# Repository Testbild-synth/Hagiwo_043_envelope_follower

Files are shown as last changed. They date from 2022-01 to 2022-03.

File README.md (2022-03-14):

# Hagiwo Eurorack Envelope Follower
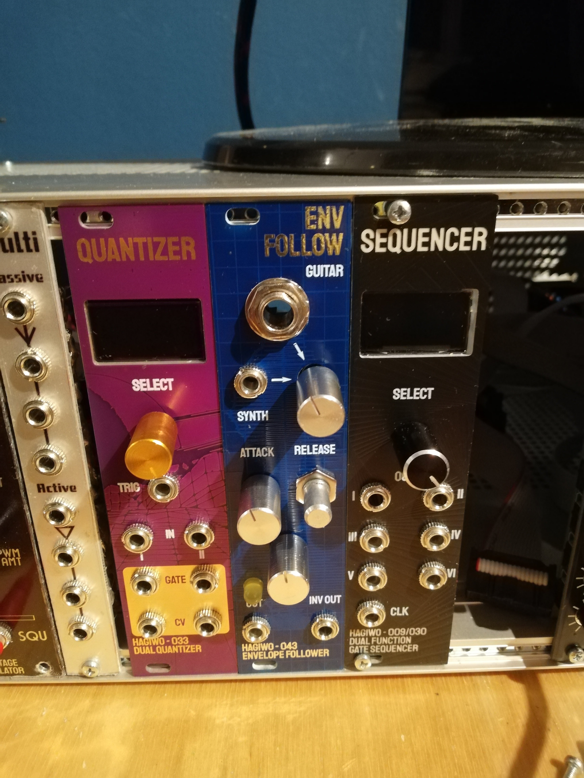
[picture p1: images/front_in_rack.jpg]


This project is a through hole PCB version the HAGIWO 043 envelope follower. I also added a guitar jack input with more amplification to be able to plug in a variety of instruments.

## STATUS: CONFIRMED WORKING! Currently on version 2, if you ordered an older version make sure that the ground connector is correctly connected to all other pcb grounds and also check that the Guitar input is going into the C3 capacitor correctly.

## Hardware and PCB
For this one I wanted to fit it all onto one PCB and make the guitar jack fit. This was quite a task and I'm afraid the pcb ended up a bit messy in the end because of this. It still works fine, but has a lot of overlapping components and you have to be careful when building it.

You can find the schematic and BOM in the root folder. 
For the PCBs, the module has one circuit PCB and one panel PCB. 
You can order them on any common PCB manufacturing service, I used JLCPCB. For the circuit PCB, standard settings should be fine.
For the panel, since it has copper exposed, make sure to choose a lead free surface finish (LeadFree HASL, ENIG) and/or spraypaint your panels so that you don't get lead on your hands.

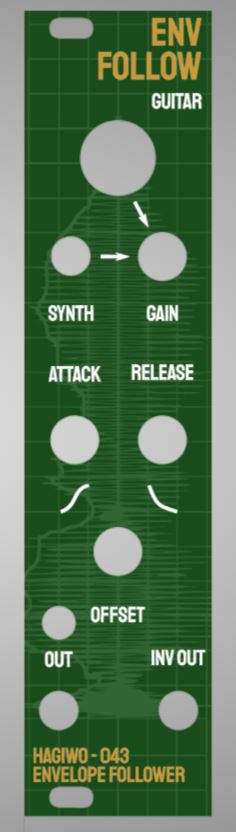
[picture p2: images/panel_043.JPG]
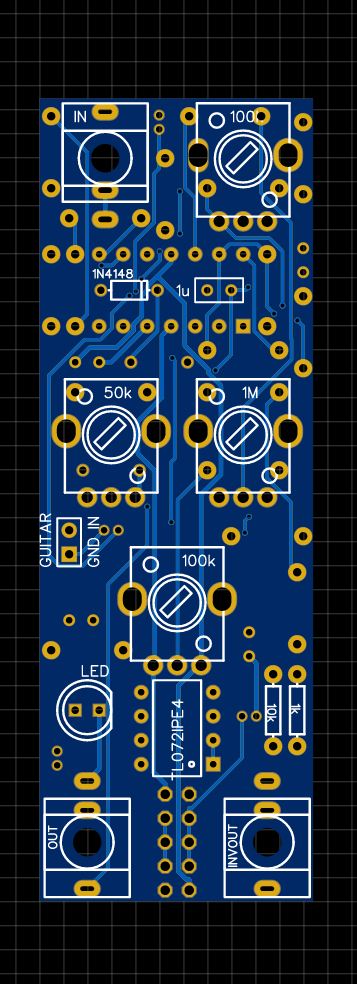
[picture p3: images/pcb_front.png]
 

For assembly, the guitar jack is optional. It will stick out and has to be connected to the rest of the pcb via wires. Look for the pads named "guitar in" and "gnd" on the pcb and connect those to the inner and outer log of a mono guitar/6.5mm jack socket.
Be sure to get a pcb mount guitar jack! we will not be mounting it to the pcb but the ["normal" round ones](https://www.conrad.de/de/p/bkl-electronic-1109001-klinken-steckverbinder-6-35-mm-buchse-einbau-vertikal-polzahl-num-2-mono-silber-1-st-732931.html) don't fit the spacing. I got [this!](https://www.reichelt.de/klinkeneinbaubuchse-6-3-mm-mono-2-pol-ebmsv-63-p36198.html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)

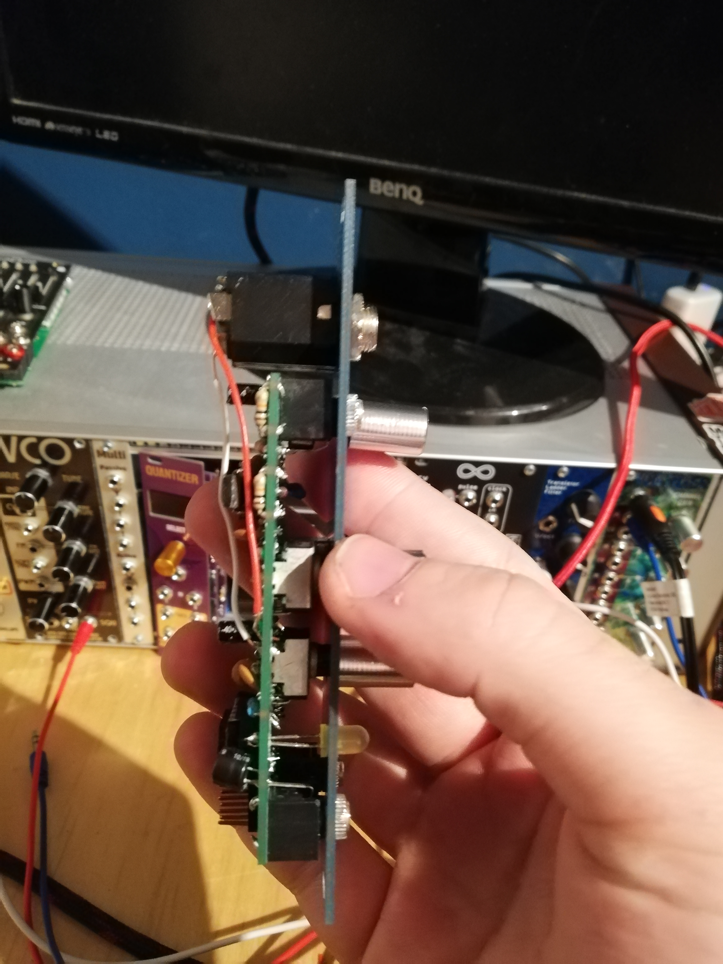
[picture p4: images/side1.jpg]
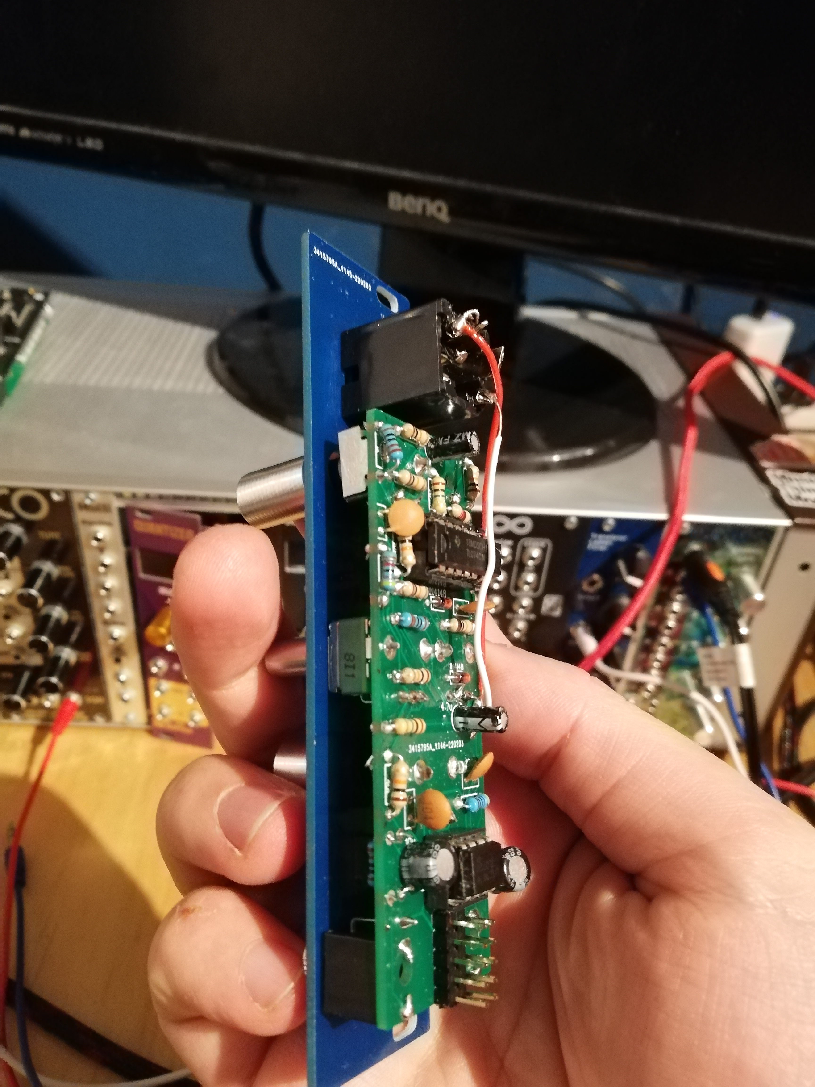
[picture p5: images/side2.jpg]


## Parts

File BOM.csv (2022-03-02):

Name | Designator | Footprint | Quantity | Comment
50k Potentiometer R09k | ATK | R09-5KΩ | 1
100k Potentiometer R09k | GAIN,OFFSET | R09-5KΩ | 2
1M Potentiometer R09k | REL | R09-5KΩ | 1
4.7u Electrolytic capacitor >25V | C1,C3 | CAP-D4.0×F1.5 | 2
1u ceramic capacitor | C2 | RAD-0.1 | 1
100n ceramic capacitor | C4,C6,C8,C9 | RAD-0.1 | 4
10u Electrolytic capacitor >25V | C5,C7 | CAP-D4.0×F1.5 | 2
1N4148 | D1,D2,D3 | SEEED-DO-35 | 3
Eurorack Power header | EP1 | EURORACK_POWER_V2 | 1
Guitar input Jack | H1 | HDR-F-2.54_1X2 | 1 | Preferably something like https://www.reichelt.de/klinkeneinbaubuchse-6-3-mm-mono-2-pol-ebmsv-63-p36198.html?r=1
Thonkiconn jack | J1,J2,J3 | THONKICONN_1 | 3
LED 5mm | LED1 | LED_LED5MM | 1
20k | R1 | R_AXIAL-0.3 | 1
22k | R2 | R_AXIAL-0.3 | 1
10k | R3,R7,R8,R9,R13,R14,R15,R16,R17 | R_AXIAL-0.3 | 10
47k | R4 | R_AXIAL-0.3 | 1
1k | R5,R12,R18 | R_AXIAL-0.3 | 3
1M | R6,R11 | R_AXIAL-0.3 | 2
4.7k | R10, R19 | R_AXIAL-0.3 | 2
TL074 DIP | U1 | DIP14 | 1
TL072 DIP | U2 | DIP8 | 1

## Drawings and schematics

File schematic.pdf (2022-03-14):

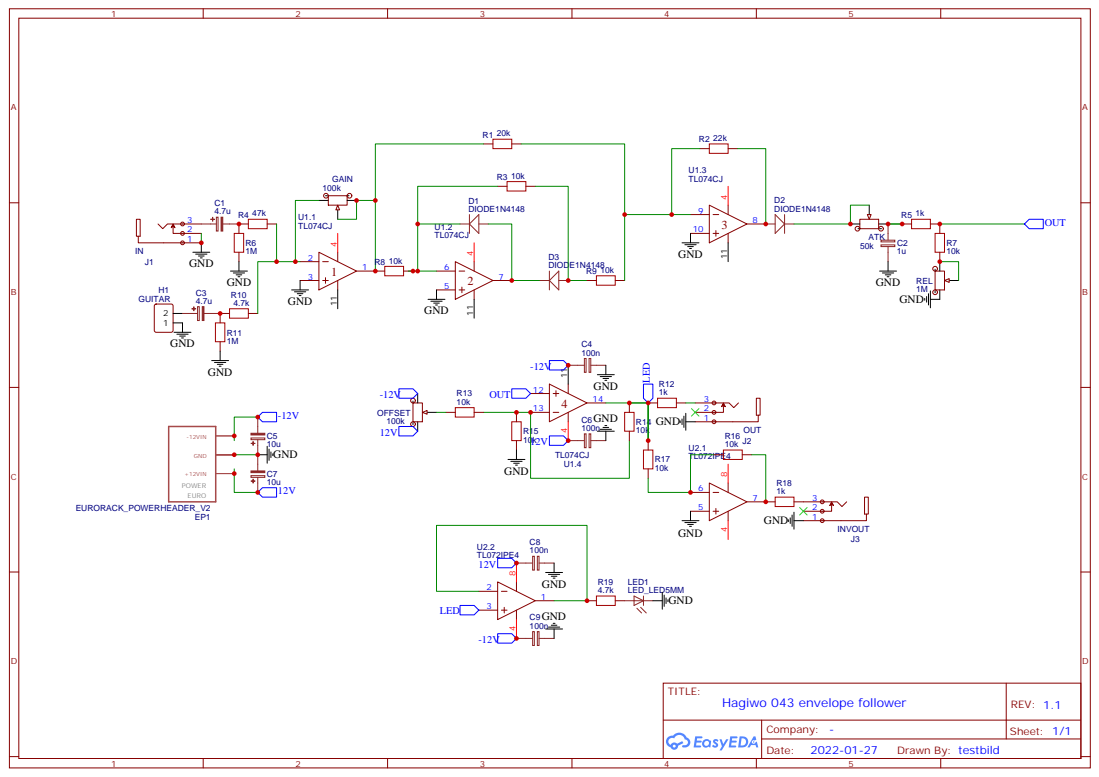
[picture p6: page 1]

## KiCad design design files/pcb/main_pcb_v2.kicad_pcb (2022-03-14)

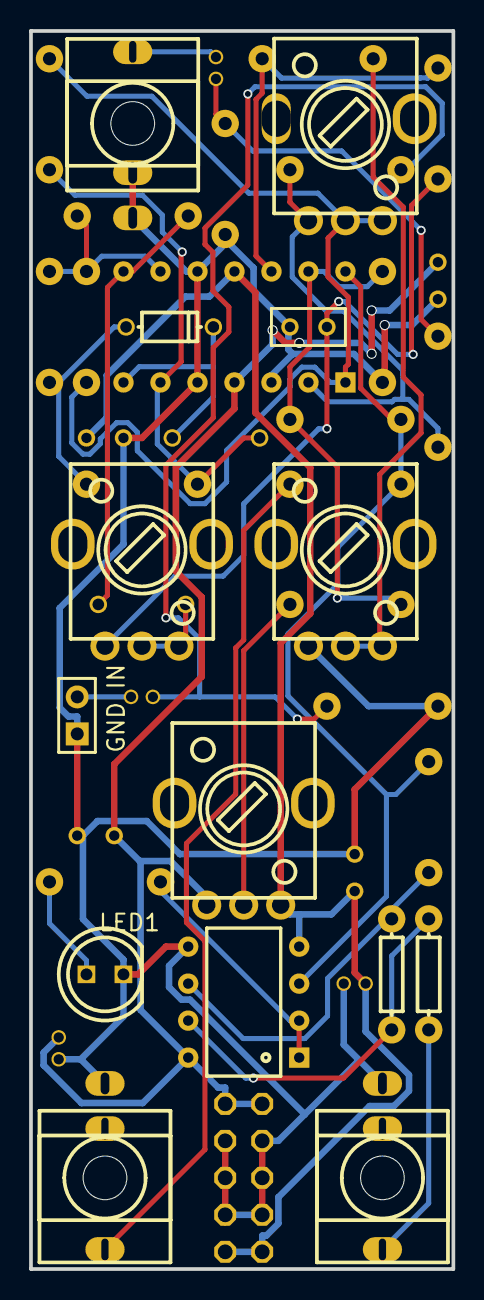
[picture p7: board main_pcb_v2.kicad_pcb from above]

Board: 2 copper layers, 29.0 x 85.0 mm, 43 parts (0 on the bottom side), 27 nets.

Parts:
ATK: 50k; R09-5KΩ
C1, C3: 4.7u; CAP-D4.0×F1.5
C2: 1u; RAD-0.1
C4, C6, C8, C9: 100n; RAD-0.1
C5, C7: 10u; CAP-D4.0×F1.5
D1, D2, D3: DIODE1N4148; SEEED-DO-35
EP1: EURORACK_POWERHEADER_V2; EURORACK_POWER_V2
GAIN: 100k; R09-5KΩ
H1: GUITAR; HDR-F-2.54_1X2
J1: IN; THONKICONN_1
J2: OUT; THONKICONN_1
J3: INVOUT; THONKICONN_1
LED1: LED_LED5MM
OFFSET: 100k; R09-5KΩ
R1: 20k; R_AXIAL-0.3
R2: 22k; R_AXIAL-0.3
R3, R7, R8, R9, R13, R14, R15, R16, R17: 10k; R_AXIAL-0.3
R4: 47k; R_AXIAL-0.3
R5, R12, R18: 1k; R_AXIAL-0.3
R6, R11: 1M; R_AXIAL-0.3
R10, R19: 4.7k; R_AXIAL-0.3
REL: 1M; R09-5KΩ
U1: TL074CJ; DIP14
U2: TL072IPE4; DIP8

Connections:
12V: C6.2, C7.1, C8.2, EP1.12, OFFSET.1, U1.4, U2.8
-12V: C4.2, C5.2, C9.2, EP1.-12, OFFSET.3, U1.11, U2.4
C1_2: C1.2, R4.2, R6.1
C2_2: ATK.1, C2.2, R5.2
D2_C: ATK.2, ATK.3, D2.C
D3_A: D3.A, R3.1, R9.2
GND: C2.1, C4.1, C5.1, C6.1, C7.2, C8.1, C9.1, EP1.GND0, EP1.GND1, EP1.GND2, EP1.GND3, EP1.GND4, EP1.GND5, H1.1, J1.1, J1.2, J2.1, J3.1, LED1.K, R6.2, R11.2, R15.2, REL.1, U1.3, U1.5, U1.10, U2.5
H1_2: C3.1, H1.2
J1_3: C1.1, J1.3
LED: R12.1, R14.1, R17.1, U1.14, U2.3
OUT: R5.1, R7.1, U1.12
R7_2: R7.2, REL.2, REL.3
R10_2: C3.2, R10.2, R11.1
R12_2: J2.3, R12.2
R13_2: OFFSET.2, R13.2
R17_2: R16.1, R17.2, U2.6
R18_2: J3.3, R18.2
R19_2: LED1.A, R19.2
U1_1: GAIN.2, GAIN.3, R1.2, R8.2, U1.1
U1_2: GAIN.1, R4.1, R10.1, U1.2
U1_6: D1.C, R3.2, R8.1, U1.6
U1_7: D1.A, D3.C, U1.7
U1_8: D2.A, R2.1, U1.8
U1_9: R1.1, R2.2, R9.1, U1.9
U1_13: R13.1, R14.2, R15.1, U1.13
U2_1: R19.1, U2.1, U2.2
U2_7: R16.2, R18.1, U2.7

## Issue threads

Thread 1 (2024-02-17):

Panel gerbers not working with JLCPCB

SPoT23, 2024-02-17:
When uploading the gerbers of the panel aren't recognized as the proper size, causing a quote of  $10390.70 for it being very large

Love to build this module, so I hope there is a quick fix for this

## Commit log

2022-02-01 Add files via upload
    Uploaded gerbers and design files
2022-02-22 slight changes to gerbers, now confirmed working!
    [main_pcb.kicad_pcb]
2022-02-22 slight changes to pcb silkscreen
    [main_pcb.kicad_pcb]
2022-02-23 upload additional images and BOM/schematic
    [BOM.csv]
2022-02-23 upload pcb image
2022-03-02 Version 1.2 fixes, changed Guitar jack orientation and resistor for more amplification!
    [BOM.csv, main_pcb.kicad_pcb]
2022-03-14 fixed grounding issue on pcb
    [main_pcb.kicad_pcb, main_pcb_v2.kicad_pcb]
